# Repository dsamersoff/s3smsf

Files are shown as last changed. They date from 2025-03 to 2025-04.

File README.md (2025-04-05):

# SMS Forwarder on ESP32 and SIM800Lv2 or Linux and Huawei GSM Modem

_Russian version of this document is documents/README_RUS.md_

### Introduction

The goal of this project is to create a device that can forward SMS messages from one phone number to another. The internet is not used anywhere, which is a fundamental decision (see [Discussion]()).

The software part is written entirely from scratch in C and is designed to work either under Linux or FreeRTOS. This means it can be part of a setup consisting of any Unix-based computer and a USB modem, or function as a standalone device.

The hardware part of the standalone device consists of an ESP32-WROOM (there are many ESP32 variants, but it must have UART2 and support 5V power), a SIM800Lv2 module (the second version has a much better antenna and supports 5V power), and an SSD1306 I2C LCD display (128x64). The display is optional and is used to show the current status.

### Changes from the Previous Release

- A diode was added to the hardware to protect the ESP32 from power overload during modem startup.
- The MP102 board was removed and replaced with a simple Type-C connector.
- Support for reading and sending multipart (concatenated) SMS messages has been implemented.
- Code refactoring was performed: heap memory is now used for storing and processing messages instead of on-stack buffers, as the latter caused hard-to-trace issues on the ESP32.

### User Guide
- Purchase a SIM card with a plan that includes a sufficient number of SMS messages, in MINI-SIM format.
- Insert the SIM card into a phone and:
  - Remove the PIN code.
  - Delete all contacts from the SIM card.
  - Add a contact named **"PRIMARY NUMBER"** (with a space, without quotes) containing the phone number to which all SMS messages will be forwarded. The number must be in international format (e.g., +7 321 987 65 43).

#### For Standalone Device Users
- Prepare a power adapter, USB 5V 2A.
- Prepare a USB type-C cable.
- Insert the SIM card into the modem.
- Turn on the power.
- Wait a few minutes and ensure that the screen displays:
  - `DM\S <version>`
  - The name of your GSM operator.
  - The phone number for forwarding.
  - Scrolling lines showing the number of messages found.

#### For Linux and USB Modem Users
- Ensure that the modem is detected, for example, as `/dev/ttyUSB0`.
- Run the program:
  ```
  ./s3smsf -p <port>
  ```
  - The program can run in the background with the `-D` flag.
  - The forwarding phone number can be specified in the command line with `-a <phone>`.
  - You can execute maintenance command right from command line with `-c <command>` e.g. `-c "++CLEAR"
  - You can adjust verbosity level with `-v ` from 3 (ERROR) to 7 (DEBUG)
  - You can redirect log output to file with `-l <filename>`
  - Or to syslog with `-L`

SMS messages sent from the **PRIMARY NUMBER** can contain control commands. Command SMS messages are not forwarded.

The following commands are available:
- `++CLEAR`	Deletes all messages from the SIM.
- `++CONTACTS`	Dumps the first 25 contacts from the SIM to the console.
- `++DUMP`	Dumps all messages from the SIM to the console.
- `++DELETE <n>`	Enables/disables deletion of received messages (n is expected to be 0 or 1).
- `++EXPIRE <n>`	Enables/disables expiration support (n is expected to be 0 or 1).
- `++FORWARD <n>`	Enables/disables forwarding support (n is expected to be 0 or 1).
- `++HEADER <n>`	Enables/disables an additional header (n is expected to be 0 or 1).
- `++LOG <n>`	Sets verbosity level; e.g., ++LOG 7 enables debug output.
- `++MULTIPART <n>`	Enables/disables multipart SMS support (n is expected to be 0 or 1).
- `++SAVED`	Dumps all messages from the hash table to the console.

### Software Description
#### Compilation
**Dependencies:** cmake > 3.16, esp-idf (for FreeRTOS version)

**Linux:**
```
cd <project folder>
mkdir build
cd build
cmake -DTARGET=linux ..
make
```

**Linux (cross-compilation):**
```
cd <project folder>
mkdir build
cd build
cmake -DTARGET=linux -DCMAKE_C_COMPILER=<path to cross compiler> ..
make
```

**FreeRTOS:**
Install `esp-idf` according to the documentation.
```
cd <project folder>
idf.py build
idf.py flash
```

**Off-line Testing:**
```
cd <project folder>
mkdir build
cd build
cmake -DTARGET=moc
make
```

#### Source Code Structure
```
components/ - Additional RTOS components, including the SSD1306 driver
documents/  - Documentation
main/       - RTOS-specific files
main-linux/ - Linux-specific files
main-moc/   - Off-line testing-specific files
shared/     - Common files for all OS
README.md
```
Platform-dependent code is mainly located in `smsf-hal.c`.

#### Known Issues
SIM800Lv2 is sensitive to the power provided, not all USB power supply will work.

### Hardware Description
The main hardware components include an ESP32 microcontroller and a SIM800Lv2 modem. The modem is connected to the microcontroller via GPIO 27 (modem TX) and GPIO 25 (modem RX), which are configured as UART2 RX and TX, respectively. An I2C LCD display is also connected, using GPIO 21 for SDA and GPIO 22 for SCL, and is powered directly from the ESP32’s 3.3V output. The SIM800Lv2 modem, however, requires a dedicated 5V power source, as it can draw over 1A during peak network activity. To handle power surges, a 4700µF/16V capacitor is included in the circuit. Additionally, an RL207 diode is used to protect the ESP32 from potential overloads caused by the modem.

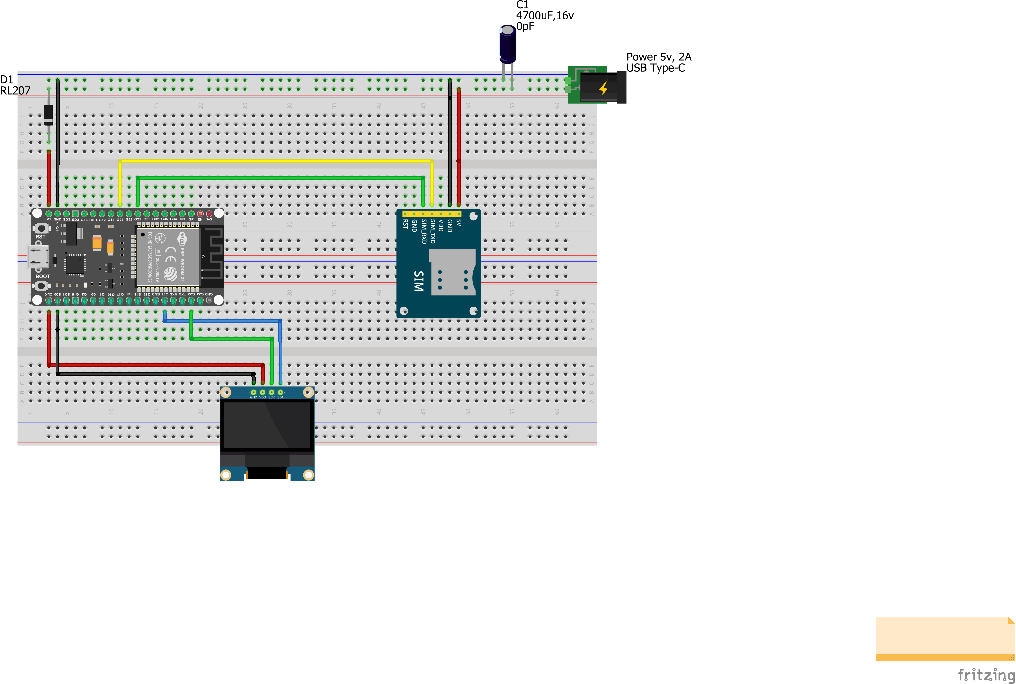
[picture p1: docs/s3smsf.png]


### Discussion
1. A SIM card can store 10 to 15 messages. If the memory is full, new messages are no longer received. At the same time, there is no way to ensure a transactional operation — if message 4 is deleted successfully but message 5 is not, the next deletion attempt for message 5 might accidentally remove a newly received message. Therefore, messages are read one by one in a loop, and `CMGL` is not used.
2. WiFi and Telegram (or similar services) are neither reliable nor secure channels for SMS forwarding. Such forwarders are becoming popular, and sooner or later, they will become targets for fraudsters. Due to the limited capabilities of microcontrollers, protection and monitoring options are also very limited.

If you want to forward messages via the internet, it is better to build a solution based on a Raspberry Pi (which can use the same SIM800L or a different modem), integrate it with a dedicated mobile app, and use push notifications — similar to how banking apps work. However, such a solution is beyond the scope of this project.

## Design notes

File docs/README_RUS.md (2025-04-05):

# SMS Forwarder on SDP32-wroom and SIM800Lv2 or Linux and Huawei GSM modem

### Введение

Цель проекта - создание коробочки (s3smsf-esp), которая умеет пересылать SMS с одного телефонного номера на другой. Интернет нигде не используется, и это принципиальное решение (см [Обсуждение]()).
Программная часть написана полностью с нуля на языке C и предназначена для работы или под управлением Linux или под управлением FreeRTOS.  Т.е. может быть частью комплекта состоящего из любого юниксового компьютера и USB модема, так и отдельно стоящей коробочки.

Аппаратная часть отдельно стоящей коробочки состоит из ESP32-WROOM (вариантов ESP32 много, важно наличие uart2 и питание от 5v), SIM800Lv2 (у второй версии гораздо лучше антенна и питание от 5v), ssd1306 i2c LCD  display 128x64 (экран не обязателен, служит для отображения текущего статуса).

### Измененния к предыдущему релизу
  - В аппартную часть добавлен диод, который защищает ESP32 от перегрузки оп питанию вов врмея запуска модема.
  - Выкинута плата MP102, вместо нее поставлен просто Type-C разъем
  - Реализована поддержка чтения и отправки multipart (concatenated) SMS
  - Произведен рефакторинг кода, для храненния и обработки сообщений используется heap память а не on-stack buffers, т.к. последние вызывают трудноуловимые проблемы у ESP32.

### Руководство пользователя
- Купить симкарту с тарифом с достаточным  количеством SMS, формат MINI-SIM
- Вставить симкарту в телефон и
    - отключить запрос пинкода
    - удалить все контакты с сим карты
    - добавить контакт "PRIMARY NUMBER" (с пробелом без ковычек) с тем номером телефона, на который будут пересылаться все SMS, номер указывается в международном формате (+7 321 987 65 43)
  #### Для пользователей коробочки
  - Подготовить адаптер питания, USB 5v 2A
  - Подготовить провод USB Type-C
  - Вставить симкарту в модем
  - Включить питание
  - Подождать несколько минут и убедиться что на экране написано
      - DM\S <version>
      - Название вашего GSM оператора
      - Номер телефона для переадрессации
      - Ниже бегут строчки с числом найденных сообщений
    #### Для пользователей Linux и USB модема
    - Убедиться, что модем найден например, как /dev/ttyUSB0
    - Запустить программу ./s3smsf -p <port>
    - Программа может работать в фоне с флагом `-D`
    - Номер для переадресации можно указать через `-a <номер>`
    - Команды обслуживания можно выполнять прямо из командной строки через `-c <команда>`, например: `-c "++CLEAR"`
    - Уровень подробности логов можно настроить флагом `-v` от 3 (ERROR) до 7 (DEBUG)
    - Логи можно перенаправить в файл через `-l <файл>`
    - Или в syslog через `-L`.

  SMS отправленные с PRIMARY NUMBER могут содержать команды для управления, командные SMS не пересылаются.

  Доступные команды:
- `++CLEAR` — удаляет все сообщения с SIM-карты.
- `++CONTACTS` — выводит в консоль первые 25 контактов с SIM-карты.
- `++DUMP` — выводит все сообщения с SIM-карты в консоль.
- `++DELETE <n>` — включает/отключает удаление входящих сообщений (`n` — 0 или 1).
- `++EXPIRE <n>` — включает/отключает поддержку срока действия (`n` — 0 или 1).
- `++FORWARD <n>` — включает/отключает переадресацию (`n` — 0 или 1).
- `++HEADER <n>` — включает/отключает дополнительный заголовок (`n` — 0 или 1).
- `++LOG <n>` — задаёт уровень логирования, например `++LOG 7` включает отладочный вывод.
- `++MULTIPART <n>` — включает/отключает поддержку multipart SMS (`n` — 0 или 1).
- `++SAVED` — выводит в консоль все сообщения из хеш-таблицы.

### Описание программной части
##### Компиляция
Зависимости: cmake > 3.16, esp-idf (для FreeRTOS версии)

Linux:

```
cd <project folder>
mkdir build
cd build
cmake -DTARGET=linux ..
make
```

Linux (cross)

```
cd <project folder>
mkdir build
cd build
cmake -DTARGET=linux -DCMAKE_C_COMPILER=<path to cross compiler> ..
make
```

FreeRTOS
Установите esp-idf в соответствии с документацией

```
cd <project folder>
idf.py build
idf.py flash
```

Off-line testing
```
cd <project folder>
mkdir build
cd build
cmake -DTARGET=moc
make
```

##### Структура исходников

```
components/ - дополнительные компоненты RTOS, в частности драйвер ssd1306
documents/  - документация
main/       - файлы специфичные для RTOS
main-linux/ - файлы специфичные для Linux
main-moc/   - файлы специфичные для off-line тестирования
shared/     - файлы общие для всех операционных систем
README.md
```
Основные платформозависимые вещи собраны в файле smsf-hal.c

##### Известные проблемы
SIM800Lv2 чувствителен к качеству питания и не с каждыи USB-блоком питания будет работать корректно.

### Описание аппаратной части
Основа аппаратной части микроконтроллер ESP32 и модем SIM800Lv2, модем подключен к GPIO 27 (TX модема) и GPIO 25 (RX модема), которые запрограммированы соотвественно на RX и TX UART2 микроконтроллера. Также к микроконтроллеру подключен I2C LCD screen GPIO 21 на SDA экрана и GPIO 22 на SCK экрана. Экран питается с вывода 3.3v микроконтроллера, модем требует самостоятельного питания 5v, т.к. в пиках (момент подключение к сети) модем может потреблять больше 1A, в систему установлен конденсатор 4700 mF/16v. Дополнительно установлен диод RL207, чтобы защитить ESP32 от перегрузки, вызванной модемом.

![s3smsf.png]()

### Обсуждение
1. Симкарта может хранить от 10 до 15 сообщений, если память заканчивается, можем перестает принимать сообщения. В тоже время, никакого способа обеспечить транзакцию нет - если нам удалось удалить сообщение 4, но не удалось удалить сообщение 5, то следующая попытка удалить сообщение 5 может привести к удалению только что полученного сообщения. Поэтому сообщения перечитываются поштучно в цикле, CMGL не используется.
2. WiFi и Telegram (и т.п.), с моей точки зрения, не является ни надежным ни безопасным каналом пересылки SMS. Подобные форвардеры набирают популярность, рано или поздно они станут объектом целенаправленной атаки жуликов, при этом в силу ограниченных возможностей микроконтроллера, возможности защиты и мониторинга тоже весьма ограничены.

Тем кому очень хочется пересылать сообщения через интернет, лучше сделать решение на базе RPI (к RPI можно приделать тот же SIM800L или взять другой модем), дополнить его специализированным приложением для телефона и использовать push-нотификацию, аналогично тому как это делают банковские приложения. Но такое решение выходит за рамки этого проекта.

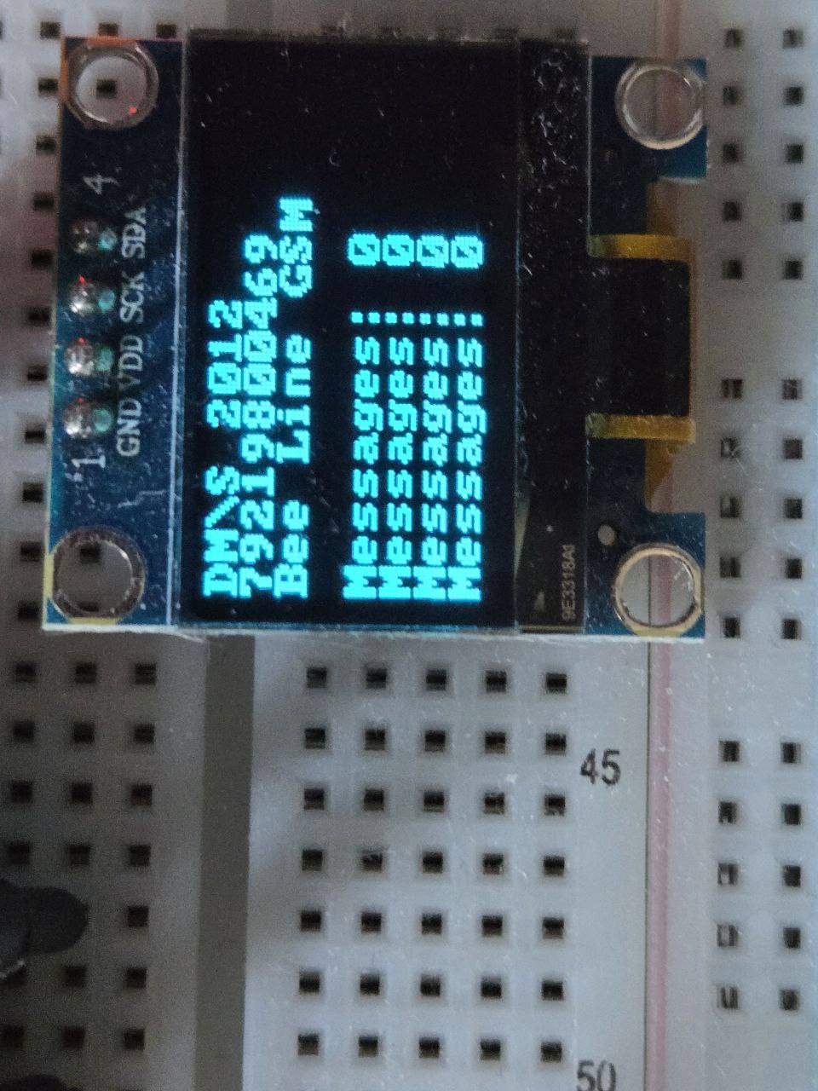
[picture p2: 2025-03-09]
docs/photo_screen.jpg

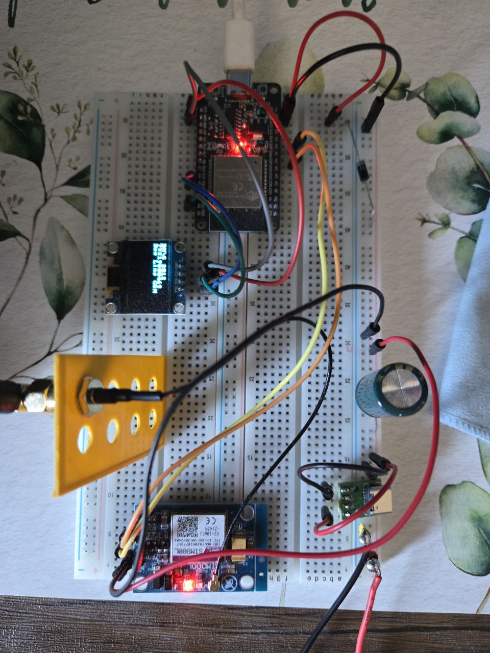
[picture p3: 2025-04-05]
docs/photo_bird_view.jpg

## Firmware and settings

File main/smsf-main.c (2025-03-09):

/*
 * Copyright (C) 2025 Dmitry Samersoff (dms@samersoff.net)
 *
 * Licensed under the Apache License, Version 2.0 (the "License");
 * you may not use this file except in compliance with the License.
 * You may obtain a copy of the License at
 *
 *        http://www.apache.org/licenses/LICENSE-2.0
 *
 * Unless required by applicable law or agreed to in writing, software
 * distributed under the License is distributed on an "AS IS" BASIS,
 * WITHOUT WARRANTIES OR CONDITIONS OF ANY KIND, either express or implied.
 * See the License for the specific language governing permissions and
 * limitations under the License.
 */

#include <stdio.h>
#include <stdlib.h>
#include <string.h>
#include <sys/fcntl.h>
#include <sys/errno.h>
#include <sys/unistd.h>
#include <sys/select.h>

#include "freertos/FreeRTOS.h"
#include "freertos/task.h"

#include "driver/uart_vfs.h"
#include "driver/uart.h"
#include "driver/gpio.h"

#include "esp_log.h"
#include "ssd1306.h"
#include "font8x8_basic.h"

#include "smsf-logging.h"
#include "smsf-hal.h"
#include "smsf-flow.h"

#define COM_DEVICE "/dev/uart/2"

extern struct smsf_options _opts;
int _uartno; // UART no

// Queue
QueueHandle_t _queue;

// static char _disp_buf[256];

// LCD  display configuration
#define SDA_PIN (GPIO_NUM_21)
#define SCL_PIN (GPIO_NUM_22)
#define RESET_PIN -1

SSD1306_t _disp; // Display device
volatile int _current_line = 0;

static void display_banner() {
    char buf[16];
    ssd1306_clear_screen(&_disp, false);
    ssd1306_contrast(&_disp, 0xff);

    snprintf(buf, sizeof(buf),"DM\\S %0X", _opts.version);
    ssd1306_display_text(&_disp, 0, buf, strlen(buf), false);
}

/* Screen layout
   0: Header
   1: Destination phone
   2: Connection status
   3:     empty line
   4: ... scroll number of messages in a loop
 */

static void display_task(void *arg) {
    char *recv_message;

    while(1) {
        if (xQueueReceive(_queue, &recv_message, 0) == pdTRUE) {
            switch ( _current_line) {
                case 1:
                  // Empty screen, clear and print the banner
                    display_banner();
                    break;
                case 3:
                    // First message in the scroll area, enable scroll before displaying message and leave empty line
                    ssd1306_software_scroll(&_disp, 4, 7);
                    _current_line += 1;
                    break;
                default:
                    break;
            }

            if (_current_line < 4) {
                // Header text
	            ssd1306_display_text(&_disp, _current_line, recv_message, strlen(recv_message), false);
            }
            else {
                // Message text
                ssd1306_scroll_text(&_disp, recv_message, strlen(recv_message), false);
            }

            _current_line += 1;
            free(recv_message);
        }
	    vTaskDelay(3000 / portTICK_PERIOD_MS);
    }
    vTaskDelete( NULL );
}


static void send_to_display(const char *format, ...) {
    va_list args;
    va_start(args, format);
    int size = vsnprintf(NULL, 0, format, args);
    char *buf = malloc(size+1);
    vsnprintf(buf, size+1, format, args);
    va_end(args);
    xQueueSend(_queue, &buf, 0);
}

static void uart_task(void *arg) {
    while(1) {
        _current_line = 1; // Not care about race

        if (flow_setup(_uartno, (notify_func_t *) send_to_display, NULL /* da ovevrirde*/) == 0) {
            while(1) {
                if (flow(_uartno, (notify_func_t *) send_to_display) != 0) {
                    // Repeat full cycle in case of errors
                    break;
                }
            }
        }
        vTaskDelay(5000 / portTICK_PERIOD_MS); // Let modem too bootstrap
    }

    vTaskDelete( NULL );
}

void app_main(void) {
    _queue = xQueueCreate(5, sizeof(char **));

    i2c_master_init(&_disp, SDA_PIN, SCL_PIN, RESET_PIN);
	ssd1306_init(&_disp, 128, 64);
    display_banner();

    log_write("display_task", "Display ready");

    if (com_open(COM_DEVICE, &_uartno) == -1) {
        log_errno("Can't open %s", COM_DEVICE);
        vTaskDelay(5000 / portTICK_PERIOD_MS);
        abort();
    }

    // Display task has lower priority then uart task
    xTaskCreate(display_task, "display_task", 2*1024, NULL, configMAX_PRIORITIES - 2, NULL);
    xTaskCreate(uart_task, "uart_task", 6 * 1024, NULL, configMAX_PRIORITIES - 1, NULL);
}

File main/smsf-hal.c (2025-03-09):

/*
 * Copyright (C) 2025 Dmitry Samersoff (dms@samersoff.net)
 *
 * Licensed under the Apache License, Version 2.0 (the "License");
 * you may not use this file except in compliance with the License.
 * You may obtain a copy of the License at
 *
 *        http://www.apache.org/licenses/LICENSE-2.0
 *
 * Unless required by applicable law or agreed to in writing, software
 * distributed under the License is distributed on an "AS IS" BASIS,
 * WITHOUT WARRANTIES OR CONDITIONS OF ANY KIND, either express or implied.
 * See the License for the specific language governing permissions and
 * limitations under the License.
 */

#include <stdio.h>
#include <stdlib.h>
#include <string.h>
#include <unistd.h>
#include <fcntl.h>
#include <errno.h>

#include "driver/uart_vfs.h"
#include "driver/uart.h"
#include "driver/gpio.h"

#include "smsf-logging.h"
#include "smsf-hal.h"

extern struct smsf_options _opts;

#define BAUDRATE 115200
#define READ_TIMEOUT 1000
#define READ_SIZE 1
#define RX_BUF_SIZE 1024

#define TXD_PIN (GPIO_NUM_25)
#define RXD_PIN (GPIO_NUM_27)

static int init_uart(int uart_no) {
    const uart_config_t uart_config = {
        .baud_rate = BAUDRATE,
        .data_bits = UART_DATA_8_BITS,
        .parity = UART_PARITY_DISABLE,
        .stop_bits = UART_STOP_BITS_1,
        .flow_ctrl = UART_HW_FLOWCTRL_DISABLE,
        .source_clk = UART_SCLK_DEFAULT,
    };

    // We won't use a buffer for sending data.
    if (uart_driver_install(uart_no, RX_BUF_SIZE, 0, 0, NULL, 0) != ESP_OK) {
        log_err("Driver installation failed");
        return -1;
    }

    uart_param_config(uart_no, &uart_config);
    uart_set_pin(uart_no, TXD_PIN, RXD_PIN, UART_PIN_NO_CHANGE, UART_PIN_NO_CHANGE);
    return 0;
}

int com_open(const char *device, int* uart_no) {
    int luart_no = -1;

    // TODO: Ugly, do it better
    if (strcmp(device, "/dev/uart/1") == 0) {
        luart_no = UART_NUM_1;
    }
    else if (strcmp(device, "/dev/uart/2") == 0) {
        luart_no = UART_NUM_2;
    }

    if (luart_no == -1) {
        log_err("Invalid device %s", device);
        return -1;
    }

    if (init_uart(luart_no) == -1) {
        return -1;
    }

//    UART addressed by number, don't need file descriptor
//    int lfd = -1;
//    if ((lfd = open(device, O_RDWR)) == -1) {
//        return -1;
//    }

    // We have a driver now installed so set up the read/write functions to use driver also.
    uart_vfs_dev_use_driver(luart_no);

    *uart_no = luart_no;
    return 0;
 }

void com_close(int uart_no) {
    // Need not to close UART
    // close(fd);
}

int com_write(int uart_no, const char *data, int data_size, int* bytes_written) {
    int bw = uart_write_bytes(uart_no, data, data_size);
    if (bw == -1) {
        *bytes_written = 0;
        return -1;
    }
    *bytes_written = bw;
    return (bw == data_size) ? 0 : -1;
}

static int com_read_impl(int uart_no, char *data, int data_size, int timeout, int* bytes_read) {
    int br = 0;
    *bytes_read = 0;
    memset(data, 0, data_size);
    data_size -= 1; // make a room for \0, decreasing local var - changes will not be saved.

    while(1) {
        int ask_size = ((data_size - *bytes_read) < READ_SIZE) ? data_size - *bytes_read : READ_SIZE;
        br = uart_read_bytes(uart_no, data + (*bytes_read), ask_size, READ_TIMEOUT);
        if (br == -1 || br == 0) { // read error or EOF, bail out
            return br;
        }
        *bytes_read += br;
        if (*bytes_read == data_size) { // All done
            return 0;
        }
    }
}

int com_read(int uart_no, char *data, int data_size, int timeout, int* bytes_read) {
    if (data_size == 0) { // nothing to do
        *bytes_read = 0;
        return 0;
    }
    int res = com_read_impl(uart_no, data, data_size - 1, timeout, bytes_read);
    data[*bytes_read] = '\0'; // ensure null termination for convenience
    return res;
}
